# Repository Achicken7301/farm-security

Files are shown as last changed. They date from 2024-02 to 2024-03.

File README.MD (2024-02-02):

# Farm Security

**Ideal structure** 

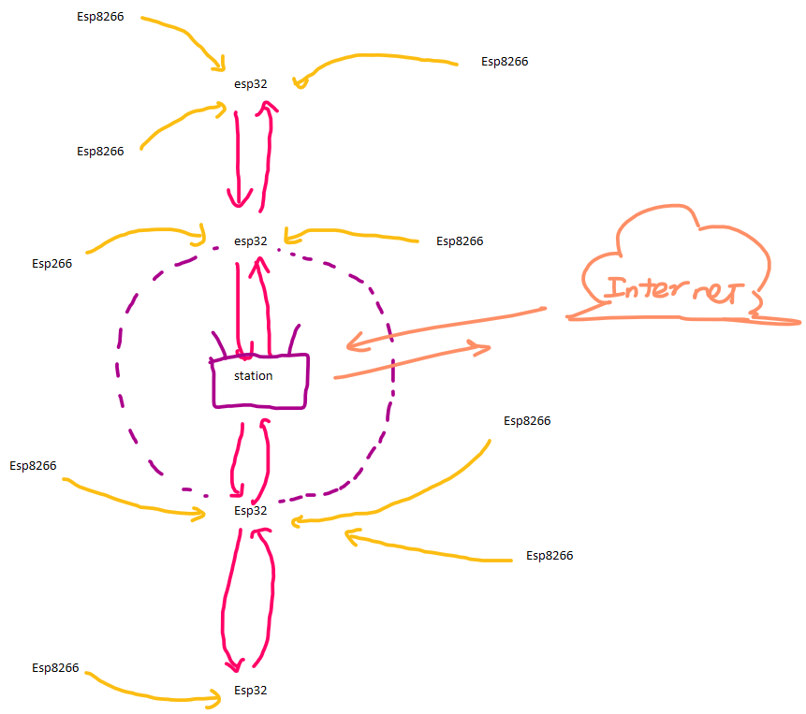
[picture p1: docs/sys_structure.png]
System Structure


The rectangel with 2 antenas in the middle is called router which can access through the internet.

The vertical ESP32 can be manage by esp-mesh, but i still can not figure this out (WILL WORK ON THIS).

EACH esp32 connect to 8266 by TCP protocols (already implement this), so ESP32 wifi mode is softAp + STA where:
- softAP: 8266 connect to.
- STA: connect to router (parent node - if in esp-mesh).

Range expectation of this project:
- Each ESP32 should connect to each-orther for 200m at least. There is Long Range (LR) mode in ESP32, but i hope, i will not use this.
- I'm not expect much about 8266 but i think it's be easy.

# Hardware

This will cost ALOT.

In each ESP32, we expect should have:
- 3 CAMERAs + IR led light (4 directions "minus" the one we attach device on).
- 3 PIR sensors (HC-SR501 - cheap PIR, range 7m) should do the trick.
- Battery holder (idk how much mAh and voltage is enough) -> WILL FIGURE THIS OUT.

In each 8266 is much simpler:
- 1 PIR sensors (HC-SR501).
- Battery holder.
- I2S microphone (I HOPE I CAN REACH THIS TAGE LOL).

# Crazy Ideas
- LOST MODE: Switch to softAP mode with free wifi name "IM LOST, CALL ME <phone-number>" if anyone connect to this wifi, create a http server with 1 button which can ring a bell in the device. -> I SHOULD CREATE A DEVICE FOR SEARCHING THIS LOL.

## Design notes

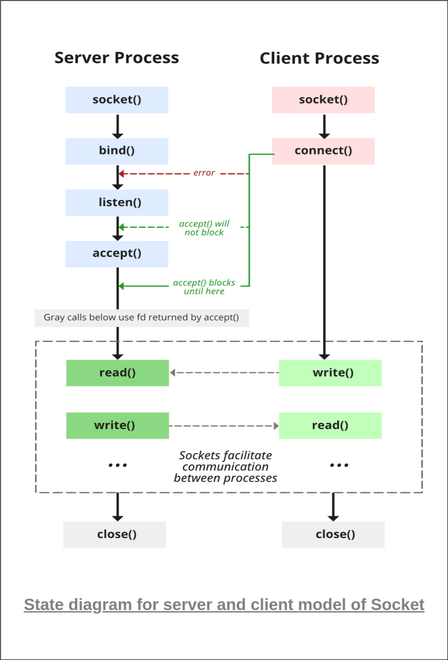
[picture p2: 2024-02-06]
docs/tcp_server_client_scoket.png

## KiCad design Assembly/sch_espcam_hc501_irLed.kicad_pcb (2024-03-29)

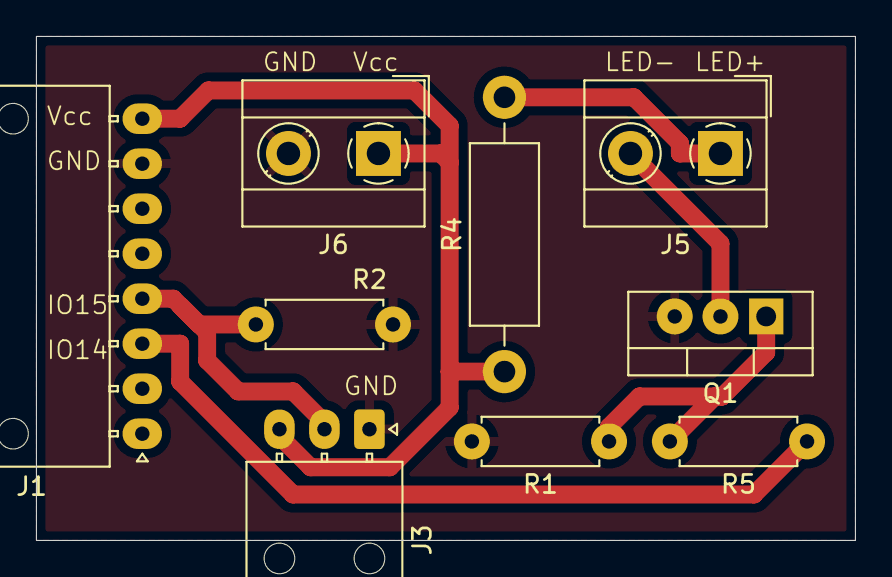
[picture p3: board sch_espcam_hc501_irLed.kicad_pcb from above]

Board: 2 copper layers, 45.5 x 28.0 mm, 9 parts (0 on the bottom side), 7 nets.

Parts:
J1: Conn_01x08_Socket; Molex_Nano-Fit_105313-xx08_1x08_P2.50mm_Horizontal
J3: HC501; Molex_Nano-Fit_105313-xx03_1x03_P2.50mm_Horizontal
J5: IR_LED_850nm; TerminalBlock_MetzConnect_Type055_RT01502HDWU_1x02_P5.00mm_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
J6: POWER; TerminalBlock_MetzConnect_Type055_RT01502HDWU_1x02_P5.00mm_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
Q1: IRF540N; TO-220-3_Vertical
R1: 100k; R_Axial_DIN0207_L6.3mm_D2.5mm_P7.62mm_Horizontal
R2, R5: 1k; R_Axial_DIN0207_L6.3mm_D2.5mm_P7.62mm_Horizontal
R4: 5.6; R_Axial_DIN0411_L9.9mm_D3.6mm_P15.24mm_Horizontal

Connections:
/GPIO15: J1.4, J3.2, R2.2
Earth: J1.7, J3.1, J6.2, Q1.3 (S), R1.2, R2.1
GPIO14: J1.3, R5.1
unnamed: J5.1, R4.2
unnamed: J5.2, Q1.2 (D)
unnamed: Q1.1 (G), R1.1, R5.2
VCC: J1.8, J3.3, J6.1, R4.1

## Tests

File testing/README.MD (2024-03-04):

# Directory Structure

## Wifi (ESP32 to ESP8266)
Goals: User can config ESP32 connect to Router using HTTPD (Apache HTTP Server).

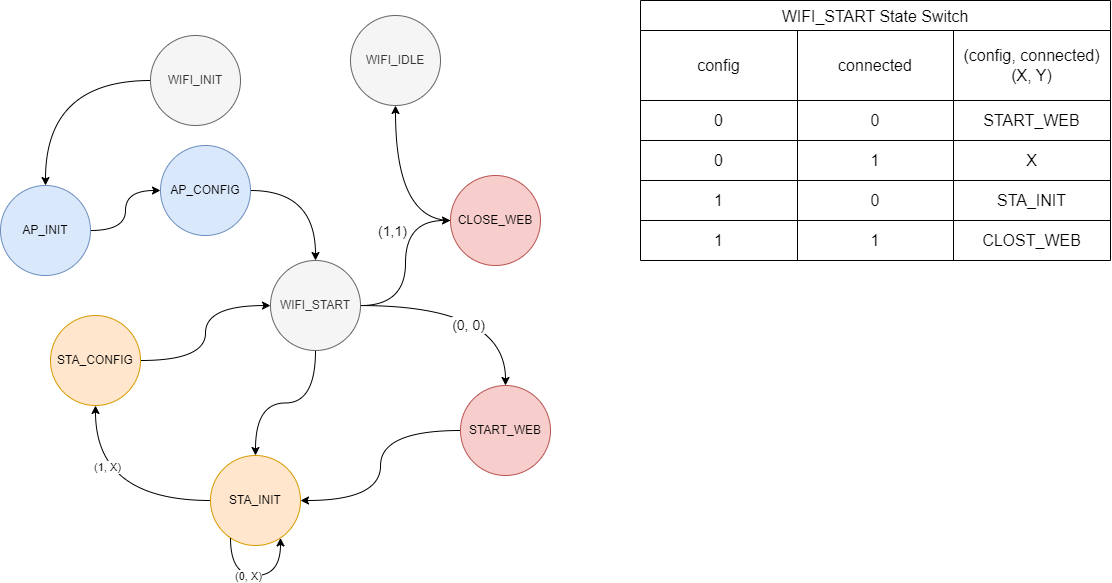
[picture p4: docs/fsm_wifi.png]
fsm_wifi
*<center>X is dont care. Example: (0,X) is no matter `connected` value if `config` is 0 WIFI_START will switch to STA_INIT.</center>*

## EPS MESH (ESP to ESP)

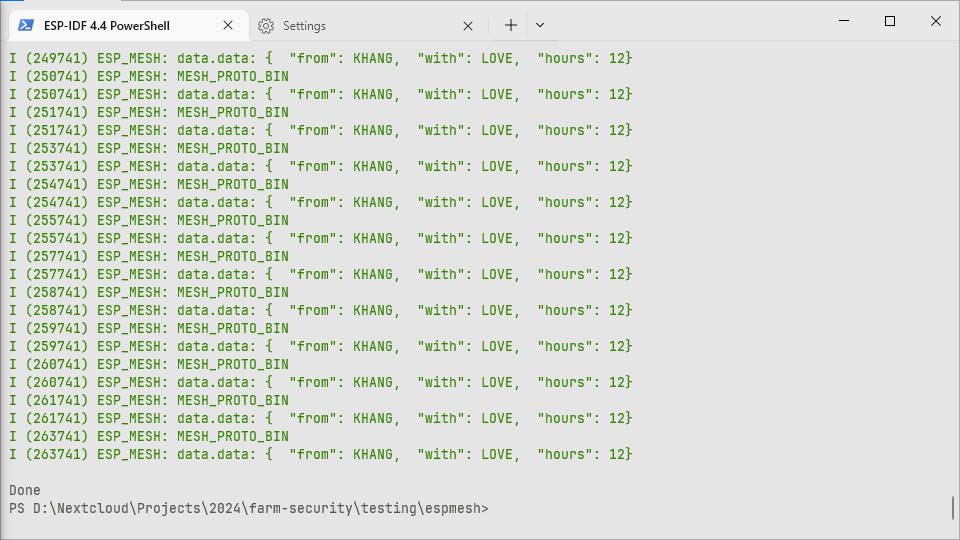
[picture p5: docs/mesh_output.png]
esp_mesh
*<center>**ESP_MESH:** OUTPUT ESP ROOT MESH.</center>*

## CAMERA_EXAMPLE

This is an example using `esp_camera.h` module to test OV2640 camera.

## Camera_tcp_client

Take picture from camera as formated as jpeg, then send to server Ipv4 ip_addr

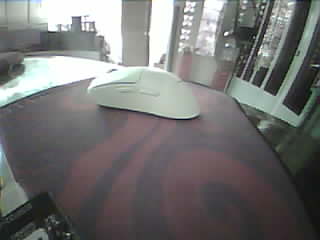
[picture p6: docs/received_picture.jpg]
cam_tcp_client


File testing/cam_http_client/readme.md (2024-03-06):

# purpose

This dir is an example of how to set up esp-station-mode, then create http-get/post and trasnfer data to httpserver.

`server_test.py` is a testing server.

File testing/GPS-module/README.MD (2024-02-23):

# Purpose of this test

- Add GPS-module to each deivces.

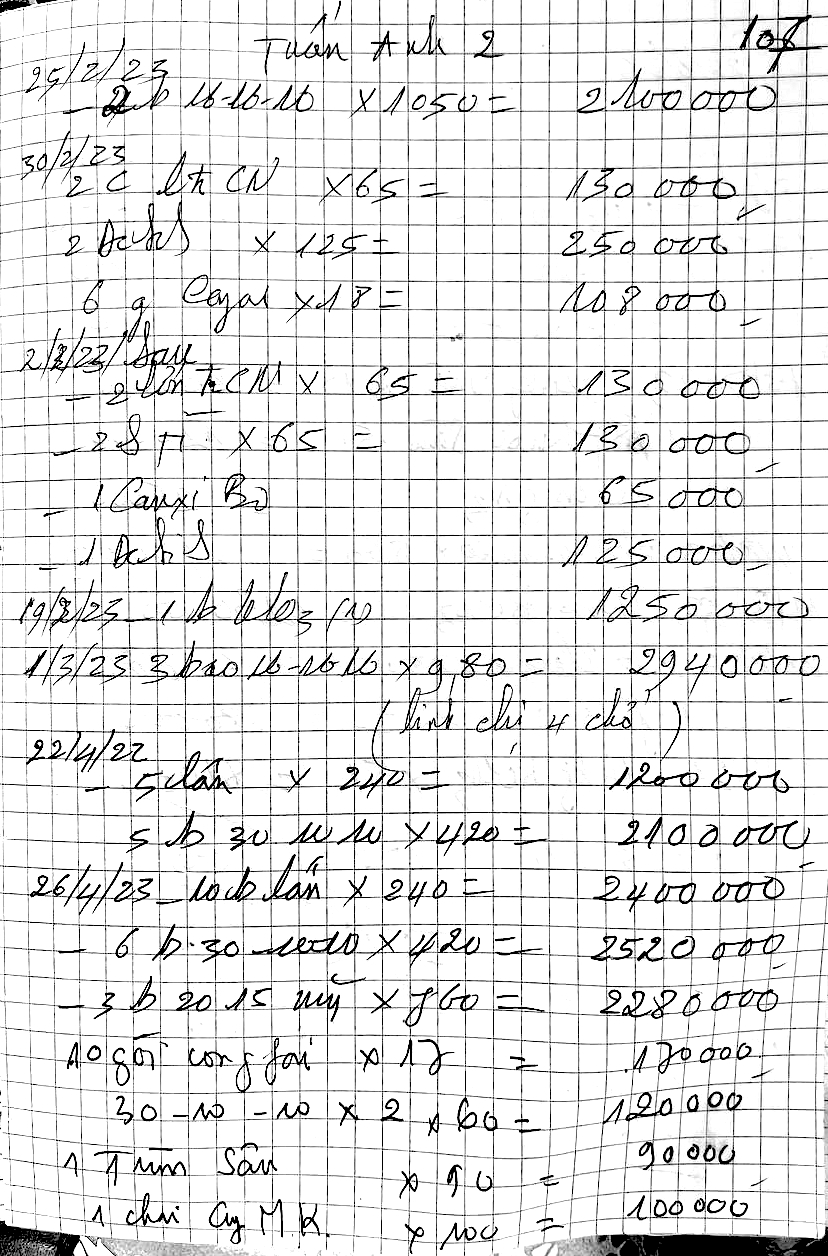
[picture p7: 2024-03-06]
testing/cam_http_client/receiving_image.jpeg

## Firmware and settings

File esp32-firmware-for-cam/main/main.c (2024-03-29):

#include "main.h"

void timerInit();

void app_main(void)
{
#if USE_MESH || USE_HTTP_SERVER || USE_TCP_SERVER || USE_STA
  ESP_ERROR_CHECK(nvs_flash_init());
  ESP_ERROR_CHECK(esp_netif_init());
  ESP_ERROR_CHECK(esp_event_loop_create_default());
  wifi_init_config_t cfg = WIFI_INIT_CONFIG_DEFAULT();
  esp_wifi_init(&cfg);
#endif

  /* Timer Init */
  timerInit();

  hc_501_gpio_init();
  ir_led_gpio_config();

  while (1)
  {
#if USE_TCP_SERVER
    fsm_ap();
    fsm_tcp_server_nonblocking();
#endif

#if USE_HTTP_CLIENT || USE_STA
    fsm_sta();
    fsm_http_client();
#endif
#if USE_CAMERA
    fsm_camera();
#endif

#if USE_MESH
    fsm_mesh();
#endif
    fsm_hc501();
    fsm_power_save();
    SCH_Dispatch();
  }
}

/**
 * @brief Hardware timer call this function every 10ms
 *
 * @param arg
 */
bool TIMER0_GROUP1_Callback(void *arg)
{
  // timerrun();
  SCH_Update();
  hc_501_reading();
  // Need to enable intr again
  // https://docs.espressif.com/projects/esp-idf/en/release-v4.4/esp32/api-reference/peripherals/timer.html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.
  ESP_ERROR_CHECK(timer_enable_intr(TIMER_GROUP_1, TIMER_0));

  return 1;
};

/**
 * @brief Config TIMER
 *
 */
void timerInit()
{
  timer_config_t ti_cfg = {
      .alarm_en = TIMER_ALARM_EN,
      .auto_reload = TIMER_AUTORELOAD_EN,
      .counter_dir = TIMER_COUNT_UP,
      .counter_en = TIMER_PAUSE,
      .divider = CPU_CLOCK, // 16bit: pre-scaler
      .intr_type = TIMER_INTR_LEVEL,

  };

  ESP_ERROR_CHECK(timer_init(TIMER_GROUP_1, TIMER_0, &ti_cfg));
  ESP_ERROR_CHECK(timer_set_counter_value(TIMER_GROUP_1, TIMER_0, 0x00));

  /**
   * @brief 1 tick = 1us
   * Timer trigger alarm when counter == 10 * 1000 (10ms)
   *
   */
  ESP_ERROR_CHECK(timer_set_alarm_value(TIMER_GROUP_1, TIMER_0, 10 * 1000));
  ESP_ERROR_CHECK(timer_enable_intr(TIMER_GROUP_1, TIMER_0));
  ESP_ERROR_CHECK(
      timer_isr_callback_add(TIMER_GROUP_1, TIMER_0, TIMER0_GROUP1_Callback, NULL, 0));

  ESP_ERROR_CHECK(timer_start(TIMER_GROUP_1, TIMER_0));
}

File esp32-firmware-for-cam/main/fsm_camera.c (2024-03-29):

/**
 * @file fsm_camera.c
 * @author Khang (banhbeovodung01@gmail.com)
 * @brief Required INIT Watch Dog (WD) and Enable PSRAM (component config ->
 * ESP32-spercific -> Support for external, SPI-connected RAM)
 * @version 0.1
 * @date 2024-03-03
 *
 * @copyright Copyright (c) 2024
 *
 */

#include "fsm_camera.h"

const char *FSM_CAMERA_TAG = "CAMERA_TAG";

#if USE_CAMERA
CameraState cState = CAM_INIT;
#else
CameraState cState = CAM_DO_NOTHING;
#endif

camera_fb_t *pic = NULL;
int isCamReady = 1;

char *get_cState(CameraState state)
{
  switch (state)
  {
  case CAM_INIT:
    return "CAM_INIT";

  case CAM_TAKE_PIC:
    return "CAM_TAKE_PIC";
  default:
    return UNKNOWN_STATE;
  }
}

/**
 * @brief Set Camera State
 *
 *
 * @param CAM_INIT Initilize camera
 * @param CAM_TAKE_PIC Take picture and store to global `pic` variable
 * @param CAM_CLEAR_PIC
 * @param CAM_DEINIT
 * @param CAM_DO_NOTHING
 */
void set_cState(CameraState state)
{
  if (!strIsEqual(get_cState(state), UNKNOWN_STATE))
  {
    ESP_LOGI(FSM_CAMERA_TAG, "Current State %s", get_cState(state));
  }
  else
  {
    ESP_LOGI(FSM_CAMERA_TAG, "Unknown State %d", state);
  }
  cState = state;
}

void takePic() { set_cState(CAM_TAKE_PIC); }
void reInitCamera() { set_cState(CAM_INIT); }

void fsm_camera()
{
  switch (cState)
  {
  case CAM_INIT:
  {
    camera_config_t camera_config = {
        .pin_pwdn = CAM_PIN_PWDN,
        .pin_reset = CAM_PIN_RESET,
        .pin_xclk = CAM_PIN_XCLK,
        .pin_sccb_sda = CAM_PIN_SIOD,
        .pin_sccb_scl = CAM_PIN_SIOC,

        .pin_d7 = CAM_PIN_D7,
        .pin_d6 = CAM_PIN_D6,
        .pin_d5 = CAM_PIN_D5,
        .pin_d4 = CAM_PIN_D4,
        .pin_d3 = CAM_PIN_D3,
        .pin_d2 = CAM_PIN_D2,
        .pin_d1 = CAM_PIN_D1,
        .pin_d0 = CAM_PIN_D0,
        .pin_vsync = CAM_PIN_VSYNC,
        .pin_href = CAM_PIN_HREF,
        .pin_pclk = CAM_PIN_PCLK,

        // XCLK 20MHz or 10MHz for OV2640 double FPS (Experimental)
        .xclk_freq_hz = 20000000,
        .ledc_timer = LEDC_TIMER_0,
        .ledc_channel = LEDC_CHANNEL_0,

        .pixel_format = PIXFORMAT_JPEG, // YUV422,GRAYSCALE,RGB565,JPEG

        // QQVGA-UXGA, For ESP32, do not use sizes above QVGA
        // when not JPEG. The performance of the ESP32-S series
        // has improved a lot, but JPEG mode always gives
        // better frame rates.
        .frame_size = FRAMESIZE_VGA,
        // .frame_size = FRAMESIZE_QVGA,
        // .frame_size = FRAMESIZE_HD,
        // 0-63, for OV series camera sensors, lower number
        // means higher quality
        .jpeg_quality = 8,
        // When jpeg mode is used, if fb_count more than one, the
        // driver will work in continuous mode.
        .fb_count = 1,
        .grab_mode = CAMERA_GRAB_WHEN_EMPTY,
    };

    // initialize the camera
    esp_err_t err = esp_camera_init(&camera_config);
    if (err != ESP_OK)
    {
      isCamReady = 0;
      ESP_LOGE(FSM_CAMERA_TAG, "Camera Init Failed");
      set_cState(CAM_DEINIT);
      break;
    }

    /* Transision base on module */
#if USE_MESH || USE_HTTP_CLIENT
    set_cState(CAM_DO_NOTHING);
#else
    set_cState(CAM_TAKE_PIC);
#endif
  }
  break;
  case CAM_CLEAR_PIC:
  {
    esp_camera_fb_return(pic);
    ESP_LOGI(FSM_CAMERA_TAG, "Cam is ready");
    isCamReady = 1;

    /* TODO: After taking picture, return to deepsleep mode, Fix this later */
    // SCH_Add(startDeepSleep, 1000, ONCE);

    set_cState(CAM_DO_NOTHING);
  }
  break;
  case CAM_TAKE_PIC:
  {
    if (isCamReady == 0)
    {
      // ESP_LOGE(FSM_CAMERA_TAG, "Camera is NOT ready");
      // set_cState(CAM_DO_NOTHING);
      break;
    }
#if USE_MESH
    if (connected2Root == 0)
    {
      // ESP_LOGE(FSM_CAMERA_TAG, "Not connected to root");
      // set_cState(CAM_DO_NOTHING);
      break;
    }
#endif // End #if USE_MESH

    ESP_LOGI(FSM_CAMERA_TAG, "Taking picture...");
    for (int i = 0; i < 4; i++)
    {
      pic = esp_camera_fb_get();
      esp_camera_fb_return(pic);
    }

    pic = esp_camera_fb_get();
    ESP_LOGI(FSM_CAMERA_TAG, "Picture taken! Its size was: %zu bytes", pic->len);

    isCamReady = 0;

    set_cState(CAM_DO_NOTHING);
  }
  break;
  case CAM_DEINIT:
  {
  }
  break;
  case CAM_DO_NOTHING:
  {
  }
  break;
  default:
    break;
  }
}

void sendPic2Mesh()
{
  if (isCamReady)
  {
    set_cState(CAM_TAKE_PIC);
  }
  else
  {
    ESP_LOGW(FSM_CAMERA_TAG, "Camera is not ready");
  }
}

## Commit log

2024-02-23 [feat] Update esp32 firmware
    Add mutiples modules (fsm), currently, fsm_http_server is NOT working.
    - fsm_tcp_server is an alternative for this, create tcp server at port 5544, then user can login using telnet or netcat. fsm_ap is a support fsm for fsm_tcp_server
    - scheduler.h is an simple scheduler implement using timer O(n) complexity.
    - fsm_mesh is needed for communicate betweent multples esp32.
2024-02-27 [feat] root connect to internet through tcp socket
2024-03-04 [feat] Camera to tcp_server
    Import esp_cam.h module,
    take frame as jpeg send to simple tcp_server created by python.
2024-03-06 [test] camera http client
    camera send data to server throught http client, instead of tcp socket.
2024-03-09 [feat] from camera to http server
    Using malloc (i WILL NOT use malloc in production code)
2024-03-09 [fxi] Fix conflict timer0 group0
    GROUP0_TIMER0 is used by some services like http client or mesh or something i dont know. Change timer fix the problem.
    [main.c]
2024-03-09 [Fix] No need allocate memory cause many crashes
    [fsm_camera.h]
2024-03-29 [test] no idea
    [led_hc501.kicad_pcb, led_hc501.kicad_sch, sch_espcam_hc501_irLed.kicad_pcb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]
2024-04-03 [SCHEMATIC] testing
    [led_hc501.kicad_pcb, led_hc501.kicad_sch]
